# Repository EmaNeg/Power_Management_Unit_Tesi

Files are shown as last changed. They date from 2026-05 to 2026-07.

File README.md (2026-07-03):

# Power Management Unit (PMU) per Sistemi Embedded






<div align="center">
  <!-- Sostituisci con i nomi reali dei file immagine esportati -->
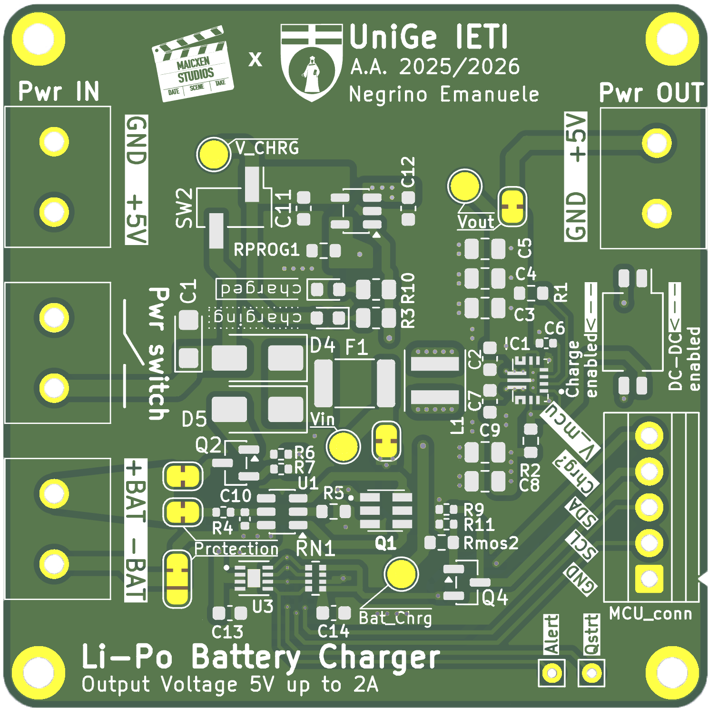
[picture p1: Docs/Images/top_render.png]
Render Top PCB
  
  &nbsp;&nbsp;&nbsp;&nbsp;&nbsp;&nbsp;&nbsp;&nbsp;&nbsp;&nbsp;&nbsp;&nbsp;&nbsp;&nbsp;&nbsp;&nbsp;&nbsp;&nbsp;
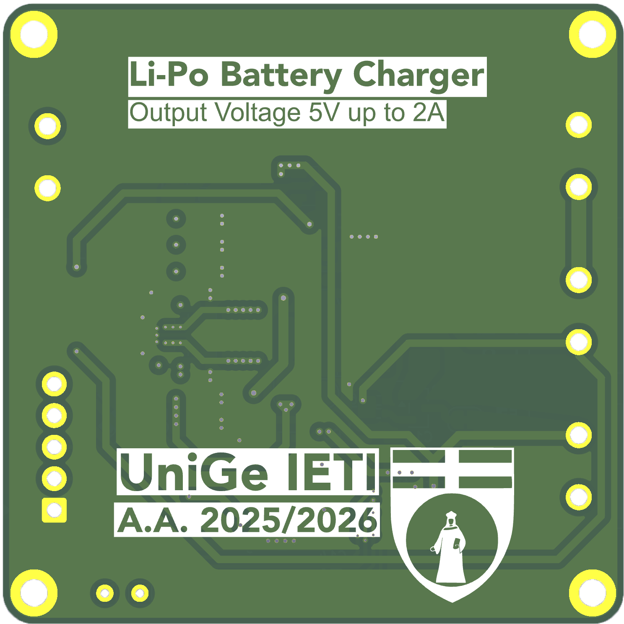
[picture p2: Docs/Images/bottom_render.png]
Render Bottom PCB
  
</div>

<br>

Questo repository contiene tutti i file di progettazione hardware, le simulazioni e le librerie software per una **Power Management Unit (PMU) integrata**, sviluppata come progetto di Tesi di Laurea Triennale in Ingegneria Elettronica e Tecnologie dell'Informazione presso l'Università degli Studi di Genova.

Il modulo (dimensioni 50x50 mm su PCB a due strati) è progettato per superare il divario tecnologico tra le tensioni variabili delle batterie ai Polimeri di Litio (Li-Po) e le specifiche di alimentazione stabili a 5V richieste dai carichi digitali, garantendo continuità di servizio e sicurezza operativa.

---

## ✨ Caratteristiche Principali (Features)

* **Power Path Management:** Commutazione automatica e trasparente tra sorgente esterna (5V) e batteria, dando priorità all'alimentazione di rete senza azzerare i transitori sul carico.
* **Conversione DC-DC:** Uscita stabile a 5V tramite convertitore Buck-Boost, operante in modo trasparente indipendentemente dallo stato di carica della cella (da 3.0V a 4.2V).
* **Ricarica Li-Po 1S:** Algoritmo CC-CV integrato basato su architettura lineare, con interruzione automatica a 4.2V.
* **Protezione Hardware (BMS):** Modulo di protezione contro sovrascarica (< 2.4V), sovraccarica (> 4.3V) e cortocircuiti.
* **Fuel Gauging I²C:** Stima accurata dello Stato di Carica (SOC) e *alert* hardware tramite algoritmo ModelGauge, senza necessità di resistenze di shunt, azzerando la deriva dell'errore.

---

## 🛠 Architettura Hardware

Il progetto è stato interamente sviluppato utilizzando **KiCad 9.0**. Il sistema si basa sui seguenti circuiti integrati:

| Sottosistema | Modello IC | Produttore | Funzione Principale |
| :--- | :--- | :--- | :--- |
| **DC-DC Converter** | TPS630701 | Texas Instruments | Convertitore Buck-Boost 2.4 MHz fisso a 5V. |
| **Battery Charger** | MCP73831 | Microchip | Controller lineare per ricarica Li-Po 1S (CC-CV). |
| **Fuel Gauge** | MAX17048 | Maxim Integrated | Sensore SOC I²C con algoritmo ModelGauge. |
| **Protection (BMS)** | DW01A + FS8205 | HM Semi / IC Fortune | IC di protezione batteria e doppio MOSFET N-Channel. |
| **Power Path** | DMP1045U-7 | Diodes Inc. | MOSFET P-Channel per commutazione automatica. |

---

## 📊 Prestazioni e Risultati Sperimentali

Il circuito è stato collaudato strumentalmente, registrando ottimi risultati in termini di efficienza energetica e stabilità del segnale:

* **Efficienza Energetica ($\eta$):** Compresa tra il **78.3%** (a pieno carico, ~1.25A) e il **90%** (a carico ridotto, ~100mA).
* **Ripple di Tensione:** Estremamente contenuto, registrando un picco massimo di **60 mV** a 300 mA (90 kHz) e **40 mV** a 1.4 A (390 kHz).
* **Carico Elettrico Massimale:** Il sistema sostiene in sicurezza carichi continui fino a **1.3A a 4.92V** (circa 6.4W in uscita) prima dell'intervento del fusibile resettabile hardware (tarato per sgancio a 1.6A).

<div align="center">
  <!-- Aggiungi nella repo l'immagine dei grafici dell'oscilloscopio se lo desideri -->
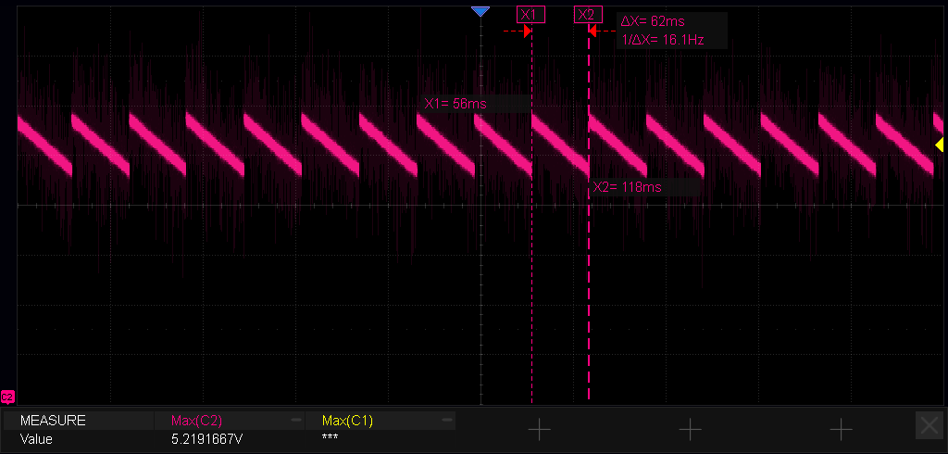
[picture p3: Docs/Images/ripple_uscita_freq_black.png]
Analisi Ripple Oscilloscopio
  
  &nbsp;&nbsp;&nbsp;&nbsp;&nbsp;&nbsp;
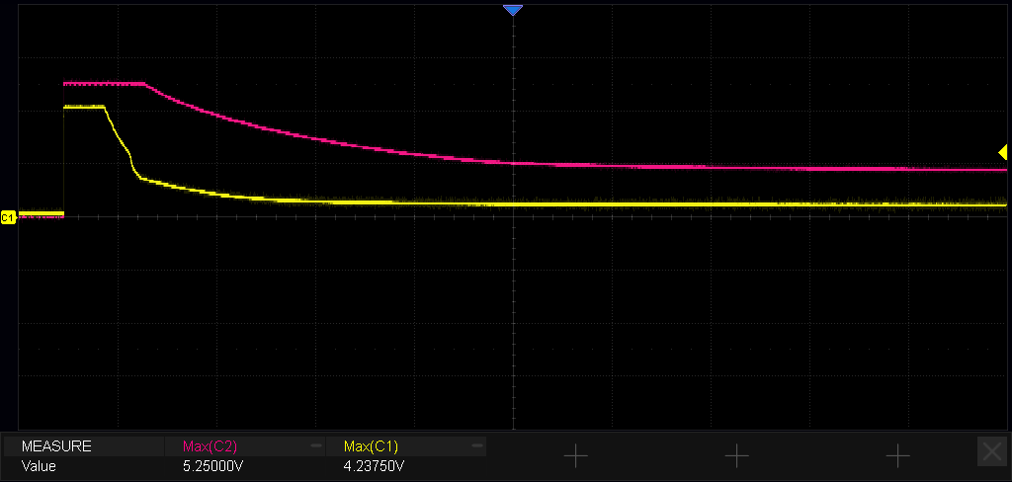
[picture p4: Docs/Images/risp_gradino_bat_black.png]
Risposta al Gradino
  
</div>

---

## 💻 Libreria Software (Firmware)

A supporto dell'hardware, è stata sviluppata una libreria firmware in **C++** dedicata al sensore MAX17048. 
La libreria permette ai microcontrollori host (es. Arduino, ESP32, STM32) di interfacciarsi facilmente con la PMU per:
- Lettura in tempo reale della tensione della cella ($V_{cell}$) e del SOC (%).
- Monitoraggio del rateo di ricarica/scarica tramite registro `CRATE`.
- Gestione interrupt hardware sul pin `ALRT` per avvisi di sotto-tensione programmabili e sleep mode per il risparmio energetico.

---

## 📁 Struttura della Repository

```text
├── Hardware/
│   ├── Kicad_files/        # File di progetto sorgente (Schematici, Layout PCB)
│   ├── Production/         # File Gerber e Drill pronti per la produzione industriale
│   ├── Assembly/           # File BOM (Bill of Materials) e CPL per assemblaggio SMT Pick & Place
│   └── 3D_Models/          # Rendering 3D della scheda top/bottom (STEP/PNG)
├── Simulations/            # File di simulazione SPICE dei blocchi funzionali (Proteus 8)
├── Firmware/               # Libreria C++ custom per MAX17048 e sketch di test (Arduino)
├── Datasheets/             # PDF dei datasheet originali dei componenti utilizzati
├── Docs/                   # Immagini, grafici di test termici/ripple, schemi e documentazione extra
└── README.md

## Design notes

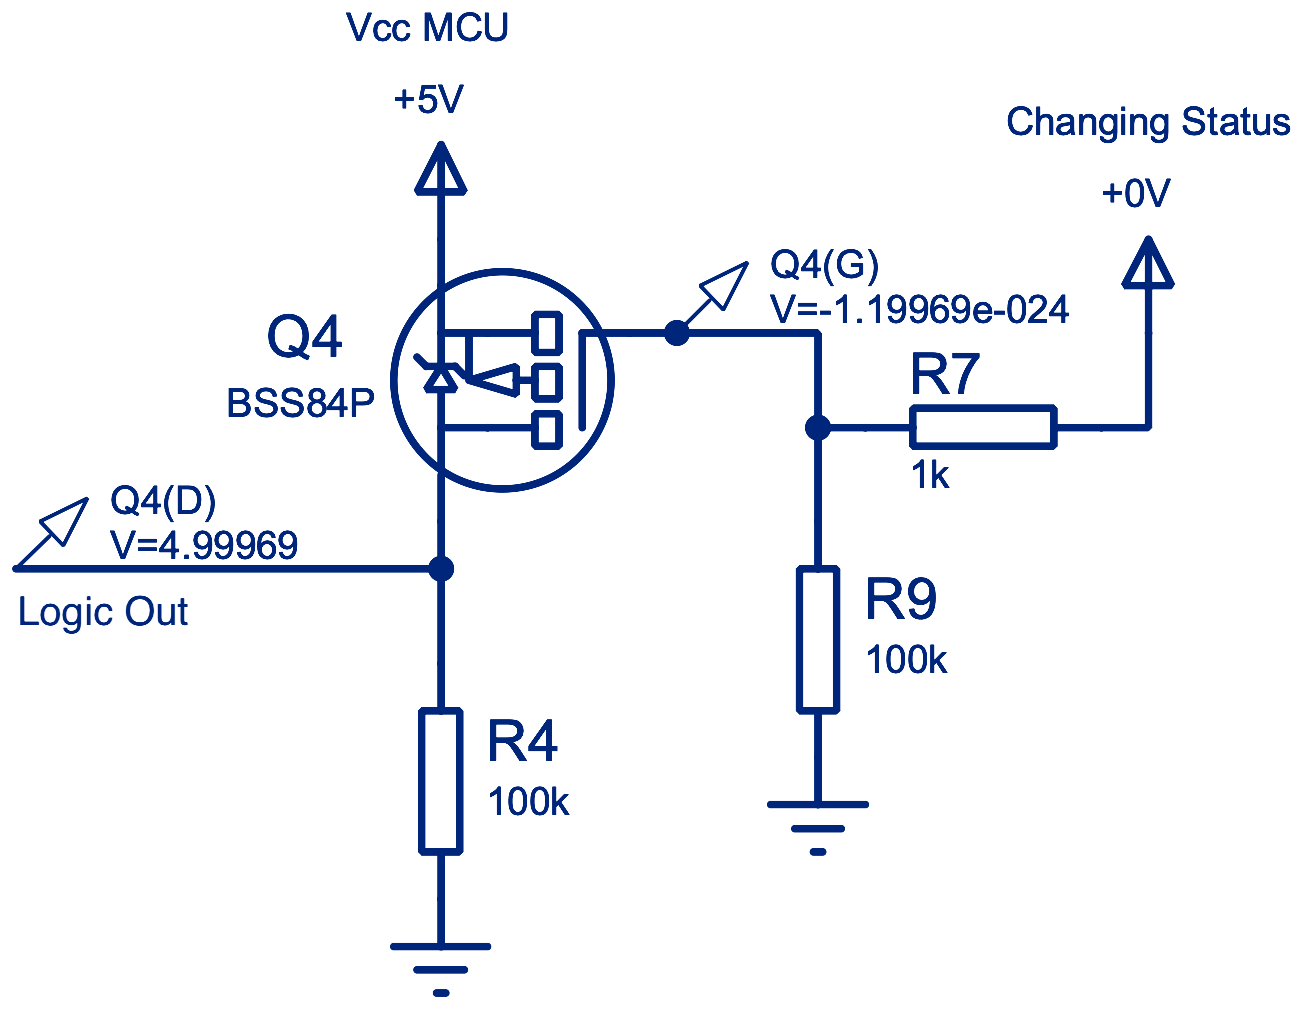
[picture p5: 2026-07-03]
Docs/Images/sim_en_charge_blue.png

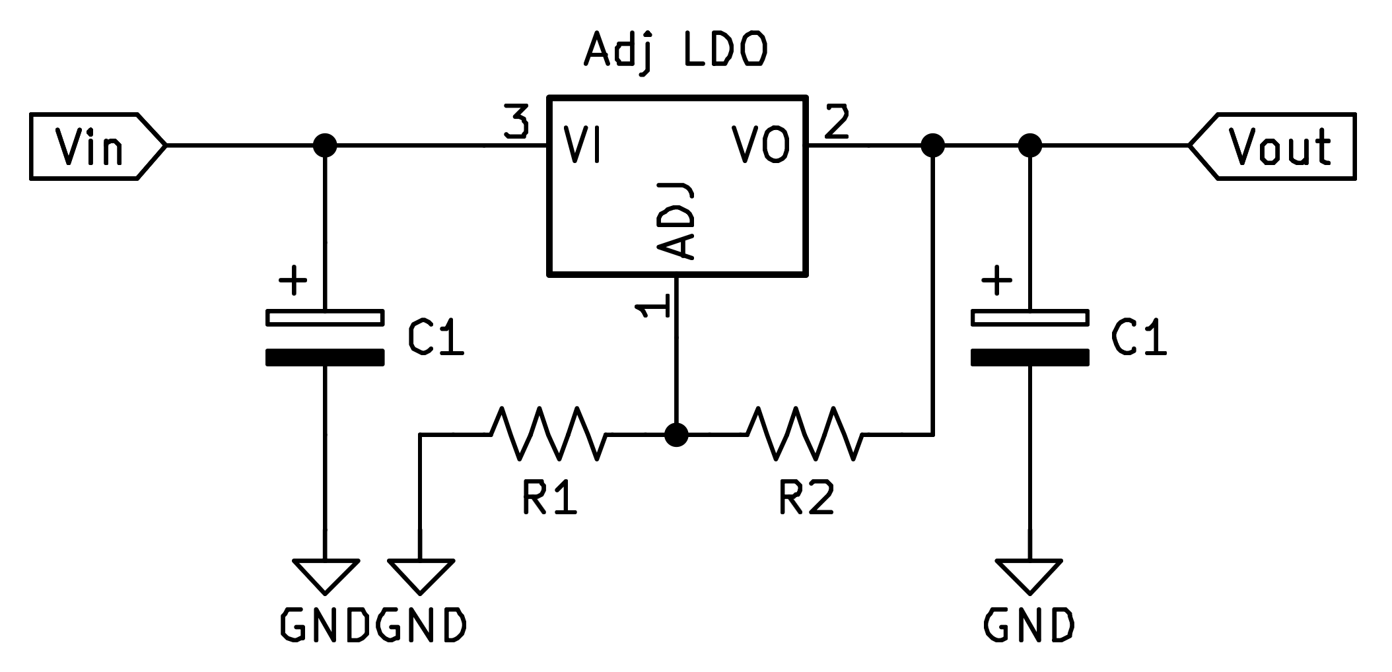
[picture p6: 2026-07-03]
Docs/Images/Adj_LDO.png

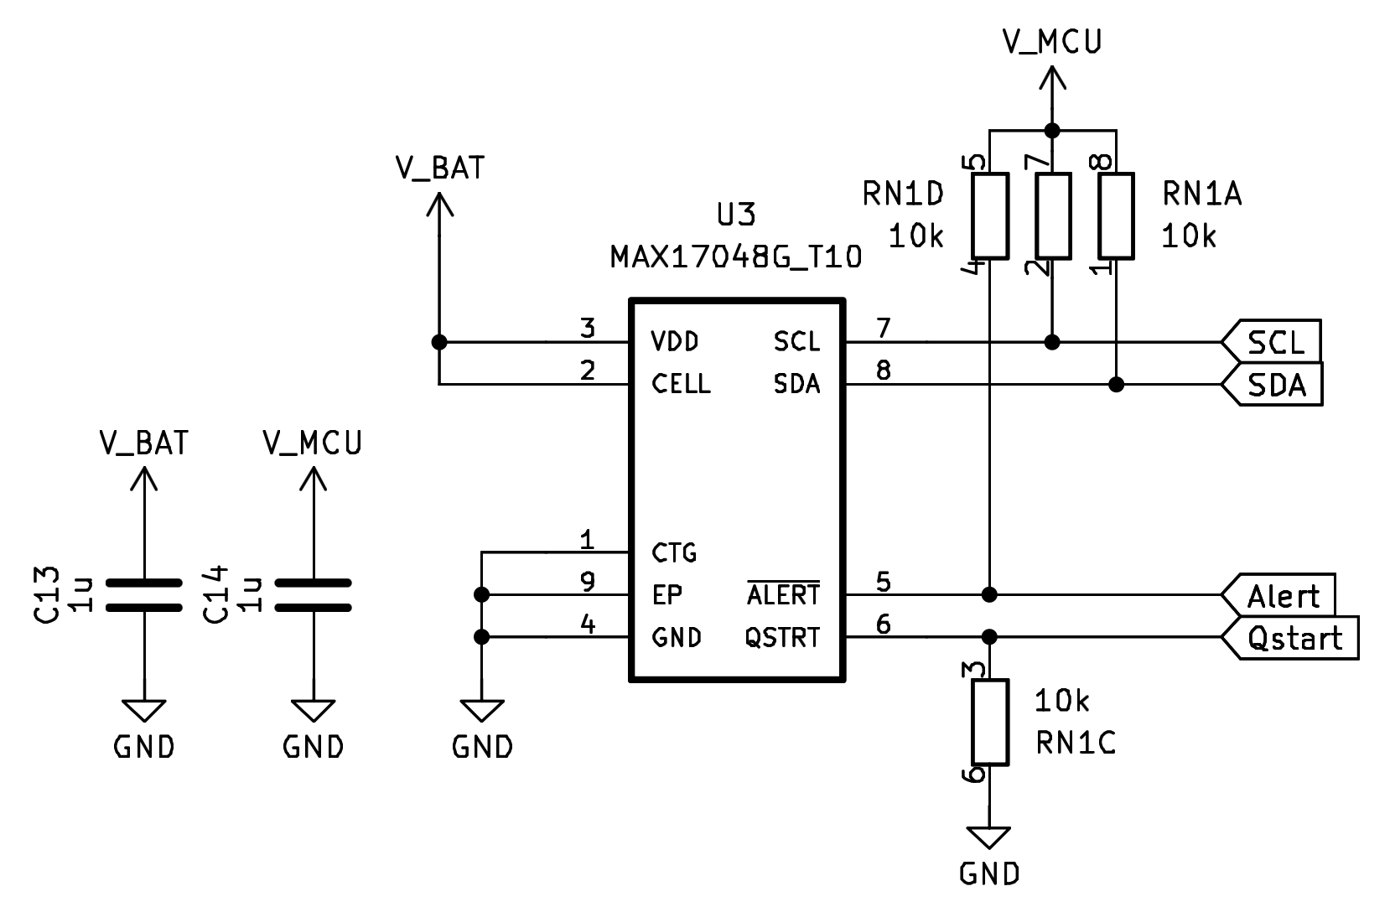
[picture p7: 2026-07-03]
Docs/Images/max17048.png

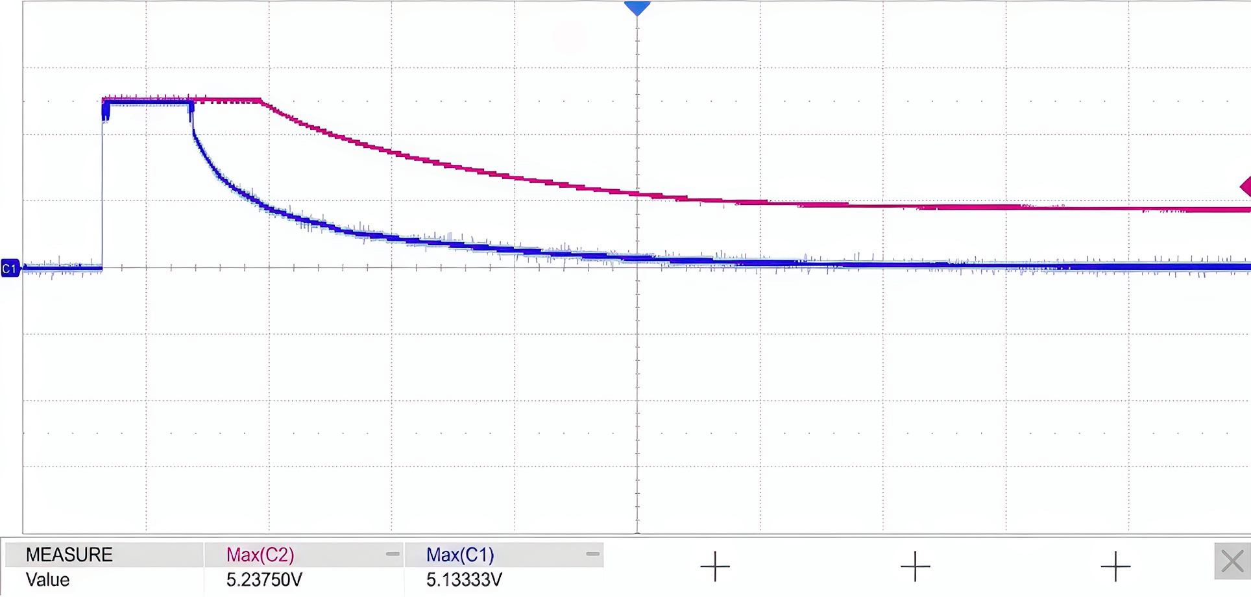
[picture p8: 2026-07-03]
Docs/Images/risp_gradino_ext.png

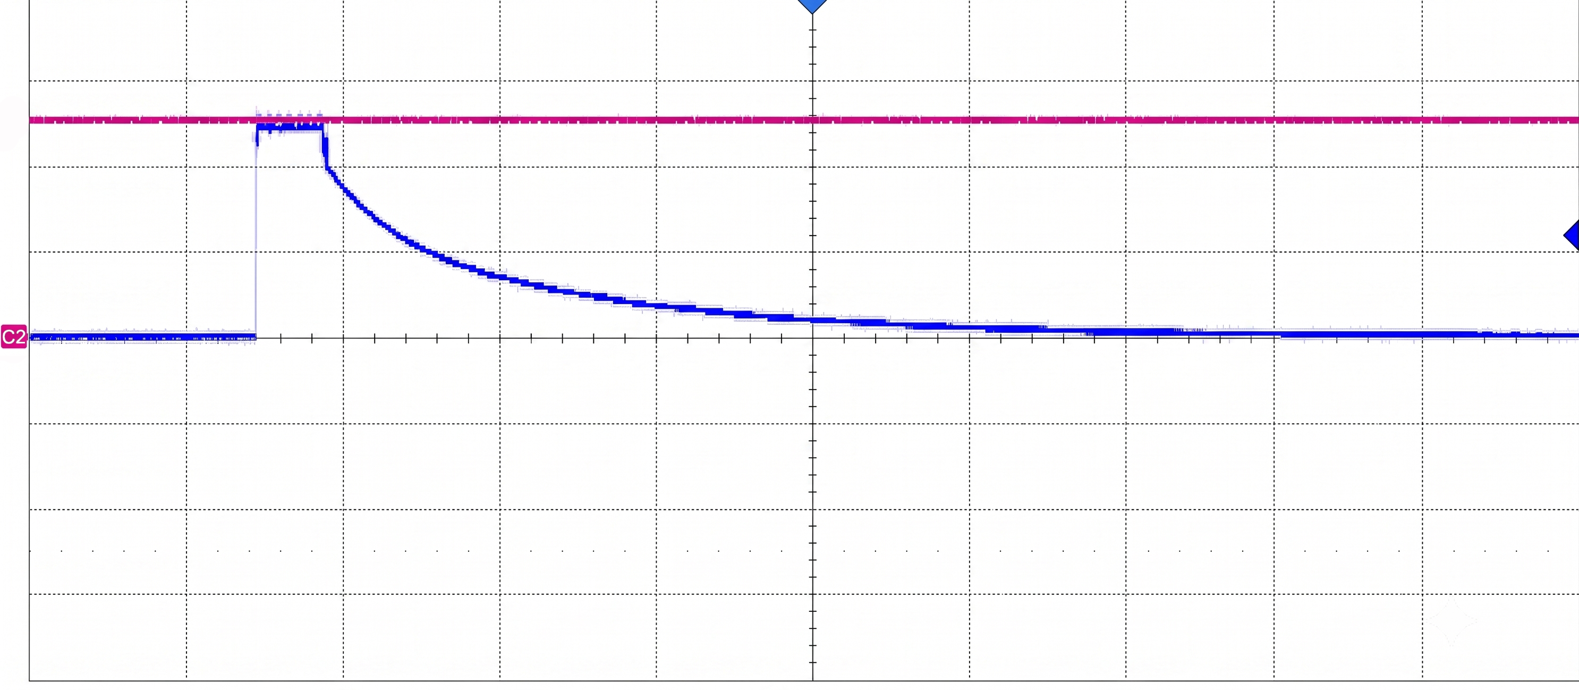
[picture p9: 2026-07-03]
Docs/Images/charge_pulse_crop.png

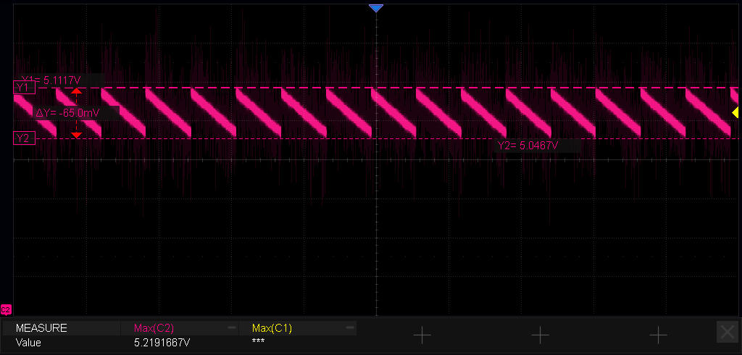
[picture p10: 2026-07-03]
Docs/Images/ripple_uscita_black.png

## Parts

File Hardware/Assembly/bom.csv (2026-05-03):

Designator | Footprint | Quantity | Value | LCSC Part #
C1 | CP_EIA-3216-18_Kemet-A | 1 | 10u
C10 | 0402 | 1 | 0.1u
C11, C12 | 0603 | 2 | 4.7u
C13, C14 | 0603 | 2 | 1u
C2, C7 | 0603 | 2 | 10u
C3, C4, C5 | 0805 | 3 | 22u
C6 | 0402 | 1 | 100n
C8, C9 | 0805 | 2 | 10u
D4, D5 | D_SMA | 2 | SS33
F1 | 1812 | 1 | 4A
IC1 | TPS630701RNMR | 1 | TPS63070RNMR
J1 | KF3012P | 1 | Ext_power_conn
J2 | KF3012P | 1 | Bat_conn
J3 | KF3012P | 1 | Out_conn
J4 | TerminalBlock_Xinya_XY308-2.54-5P_1x05_P2.54mm_Horizontal | 1 | MCU_conn
L1 | L_Coilcraft_XxL4020 | 1 | 1.5u
LED_A1 | 0603 | 1 | LED_amber
LED_G1 | 0603 | 1 | LED_green
Q1 | FS8205 | 1 | FS8205
Q2 | SOT-23-GATE | 1 | DMP1045U-7
Q4 | SOT-23 | 1 | BSS84
R1 | 0603 | 1 | 100k
R10, R3 | 0805 | 2 | 470R
R11, R6, R9 | 0402 | 3 | 100k
R2 | 0603 | 1 | 10k
R4, R7 | 0402 | 2 | 100R
R5, RMOS2 | 0603 | 2 | 1k
RN1 | R_Array_Convex_4x0402 | 1 | 10k
RPROG1 | 0603 | 1 | 2k
SW1 | KF3012P | 1 | Power_sw_conn
SW2 | PinHeader_1x02_P2.54mm_Vertical_SMD_Pin1Left | 1 | Switch_pins
SW3 | SW_DIP_SPSTx02_Slide_KingTek_DSHP02TS_W7.62mm_P1.27mm | 1 | SW_DIP_x02
TP1 | Pin_D0.7mm_L6.5mm_W1.8mm_FlatFork | 1 | Alert
TP2 | TestPoint_Pad_D2.0mm | 1 | Vout
TP3 | Pin_D0.7mm_L6.5mm_W1.8mm_FlatFork | 1 | Qstart
TP4 | TestPoint_Pad_D2.0mm | 1 | V_CHRG
TP6 | TestPoint_Pad_D2.0mm | 1 | Vin
TP7 | TestPoint_Pad_D2.0mm | 1 | Bat_Chrg
U1 | SOT-23-6 | 1 | DW01A
U2 | SOT-23-5 | 1 | MCP73831-2-OT
U3 | SON50P200X200X80-9N | 1 | MAX17048G_T10

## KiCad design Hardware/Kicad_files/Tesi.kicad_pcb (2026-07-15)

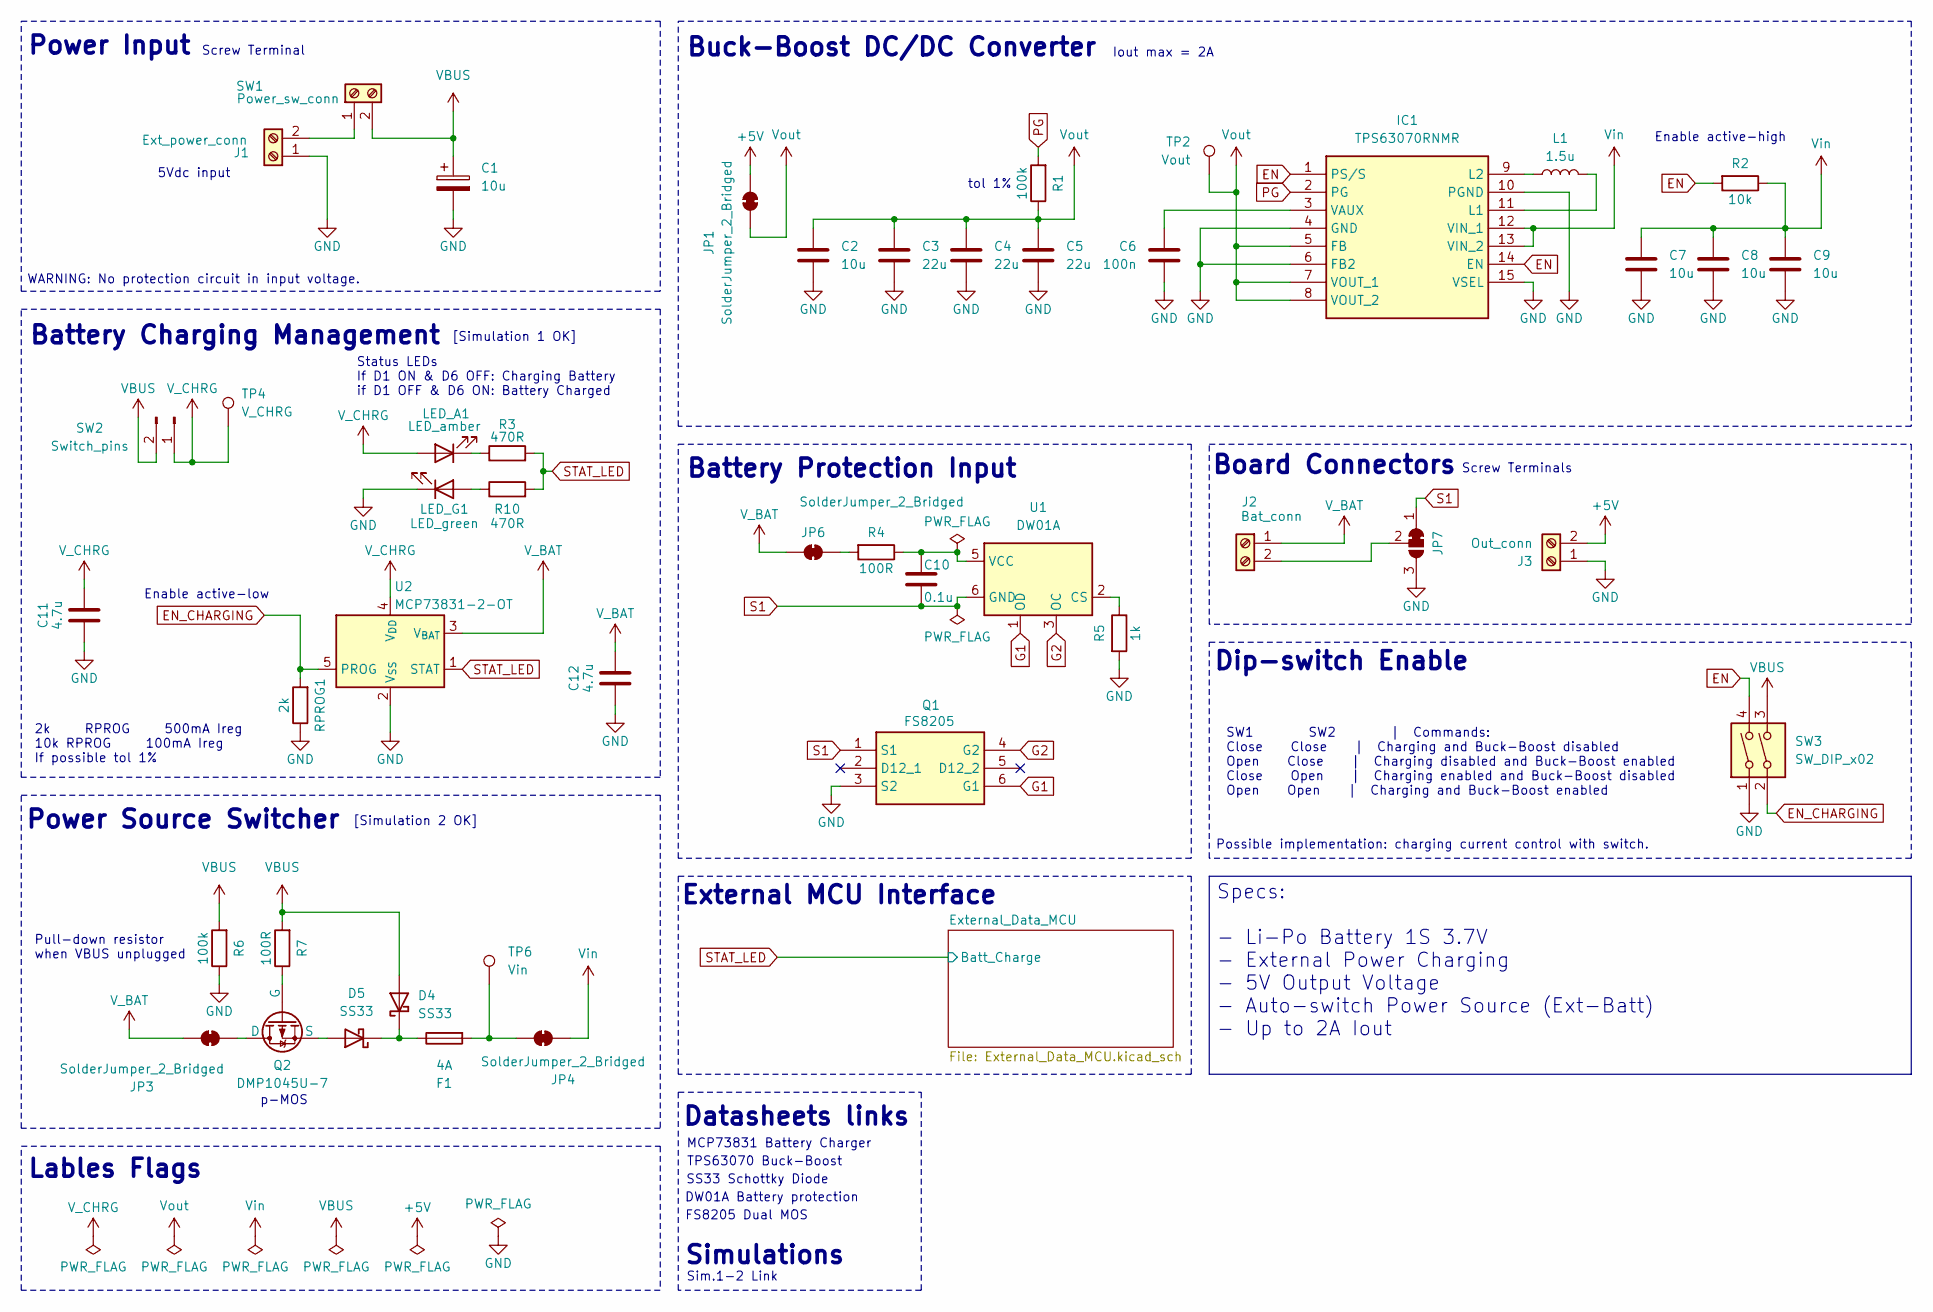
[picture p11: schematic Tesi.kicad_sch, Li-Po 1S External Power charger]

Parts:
C1: 10u; CP_EIA-3216-18_Kemet-A
C2, C7: 10u; C_0603_1608Metric
C3, C4, C5: 22u; C_0805_2012Metric
C6: 100n; C_0402_1005Metric
C8, C9: 10u; C_0805_2012Metric
C10: 0.1u; C_0402_1005Metric
C11, C12: 4.7u; C_0603_1608Metric
D4, D5: SS33; D_SMA
F1: 4A; Fuse_1812_4532Metric_Pad1.30x3.40mm_HandSolder
IC1: TPS63070RNMR; TPS630701RNMR; Manufacturer_Part_Number TPS63070RNMR; Mouser Part Number 595-TPS63070RNMR
J1: Ext_power_conn; KF3012P
J2: Bat_conn; KF3012P
J3: Out_conn; KF3012P
JP1, JP3, JP4, JP6: SolderJumper_2_Bridged; SolderJumper-2_P1.3mm_Bridged_RoundedPad1.0x1.5mm
JP7: SolderJumper_3_Bridged12; SolderJumper-3_P1.3mm_Bridged12_RoundedPad1.0x1.5mm_NumberL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
L1: 1.5u; L_Coilcraft_XxL4020
LED_A1: LED_amber; LED_0603_1608Metric
LED_G1: LED_green; LED_0603_1608Metric
Q1: FS8205; Manufacturer_Part_Number FS8205
Q2: DMP1045U-7; SOT-23-GATE
R1: 100k; R_0603_1608Metric
R2: 10k; R_0603_1608Metric
R3, R10: 470R; R_0805_2012Metric
R4, R7: 100R; R_0402_1005Metric
R5: 1k; R_0603_1608Metric
R6: 100k; R_0402_1005Metric
RPROG1: 2k; R_0603_1608Metric
SW1: Power_sw_conn; KF3012P
SW2: Switch_pins; PinHeader_1x02_P2.54mm_Vertical_SMD_Pin1Left
SW3: SW_DIP_x02; SW_DIP_SPSTx02_Slide_KingTek_DSHP02TS_W7.62mm_P1.27mm
TP2: Vout; TestPoint_Pad_D2.0mm
TP4: V_CHRG; TestPoint_Pad_D2.0mm
TP6: Vin; TestPoint_Pad_D2.0mm
U1: DW01A; SOT-23-6
U2: MCP73831-2-OT; SOT-23-5

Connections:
+5V: J3.2, JP1.2 (B)
EN: IC1.1 (PS/S), IC1.14 (EN), R2.2, SW3.4
EN_CHARGING: RPROG1.2, SW3.2, U2.5 (PROG)
G1: Q1.6 (G1), U1.1 (OD)
G2: Q1.4 (G2), U1.3 (OC)
GND: C1.2, C2.2, C3.2, C4.2, C5.2, C6.2, C7.2, C8.2, C9.2, C11.1, C12.1, IC1.4 (GND), IC1.6 (FB2), IC1.10 (PGND), IC1.15 (VSEL), J1.1, J3.1, JP7.3 (B), LED_G1.1 (K), Q1.3 (S2), R5.2, R6.1, RPROG1.1, SW3.1, U2.2 (V_{SS}); also elsewhere on the board
unnamed: D4.1 (K), D5.1 (K), F1.1
unnamed: D5.2 (A), Q2.3 (S)
unnamed: IC1.11 (L1), L1.2
unnamed: IC1.9 (L2), L1.1
unnamed: C6.1, IC1.3 (VAUX)
unnamed: J1.2, SW1.1
unnamed: J2.2, JP7.2 (C)
unnamed: JP3.2 (B), Q2.1 (D)
unnamed: F1.2, JP4.1 (A), TP6.1
unnamed: JP6.2 (B), R4.2
unnamed: LED_A1.1 (K), R3.1
unnamed: LED_G1.2 (A), R10.1
unnamed: Q2.2 (G), R7.1
unnamed: R5.1, U1.2 (CS)
unnamed: C10.2, R4.1, U1.5 (VCC)
PG: IC1.2 (PG), R1.2
S1: C10.1, JP7.1 (A), Q1.1 (S1), U1.6 (GND)
STAT_LED: R3.2, R10.2, U2.1 (STAT); also elsewhere on the board
VBUS: C1.1, D4.2 (A), R6.2, R7.2, SW1.2, SW2.2, SW3.3
V_BAT: C12.2, J2.1, JP3.1 (A), JP6.1 (A), U2.3 (V_{BAT}); also elsewhere on the board
V_CHRG: C11.2, LED_A1.2 (A), SW2.1, TP4.1, U2.4 (V_{DD})
Vin: C7.1, C8.1, C9.1, IC1.12 (VIN_1), IC1.13 (VIN_2), JP4.2 (B), R2.1
Vout: C2.1, C3.1, C4.1, C5.1, IC1.5 (FB), IC1.7 (VOUT_1), IC1.8 (VOUT_2), JP1.1 (A), R1.1, TP2.1

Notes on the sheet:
tol 1%
Power Input
Buck-Boost DC/DC Converter
Lables Flags
Power Source Switcher
Enable active-low
2k RPROG 500mA Ireg 10k RPROG 100mA Ireg If possible tol 1%
Iout max = 2A
Battery Protection Input
[Simulation 2 OK]
Simulations
Enable active-high
MCP73831 Battery Charger
p-MOS
Screw Terminals
External MCU Interface
TPS63070 Buck-Boost
Battery Charging Management
5Vdc input
Datasheets links
FS8205 Dual MOS
[Simulation 1 OK]
DW01A Battery protection
Possible implementation: charging current control with switch.
Board Connectors
SW1 SW2 | Commands: Close Close | Charging and Buck-Boost disabled Open Close | Charging disabled and Buck-Boost enabled Close Open | Charging enabled and Buck-Boost disabled Open Open | Charging and Buck-Boost enabled
SS33 Schottky Diode
WARNING: No protection circuit in input voltage.
Status LEDs If D1 ON & D6 OFF: Charging Battery if D1 OFF & D6 ON: Battery Charged
Dip-switch Enable
Screw Terminal
Pull-down resistor when VBUS unplugged
Sim.1-2 Link
Specs: - Li-Po Battery 1S 3.7V - External Power Charging - 5V Output Voltage - Auto-switch Power Source (Ext-Batt) - Up to 2A Iout

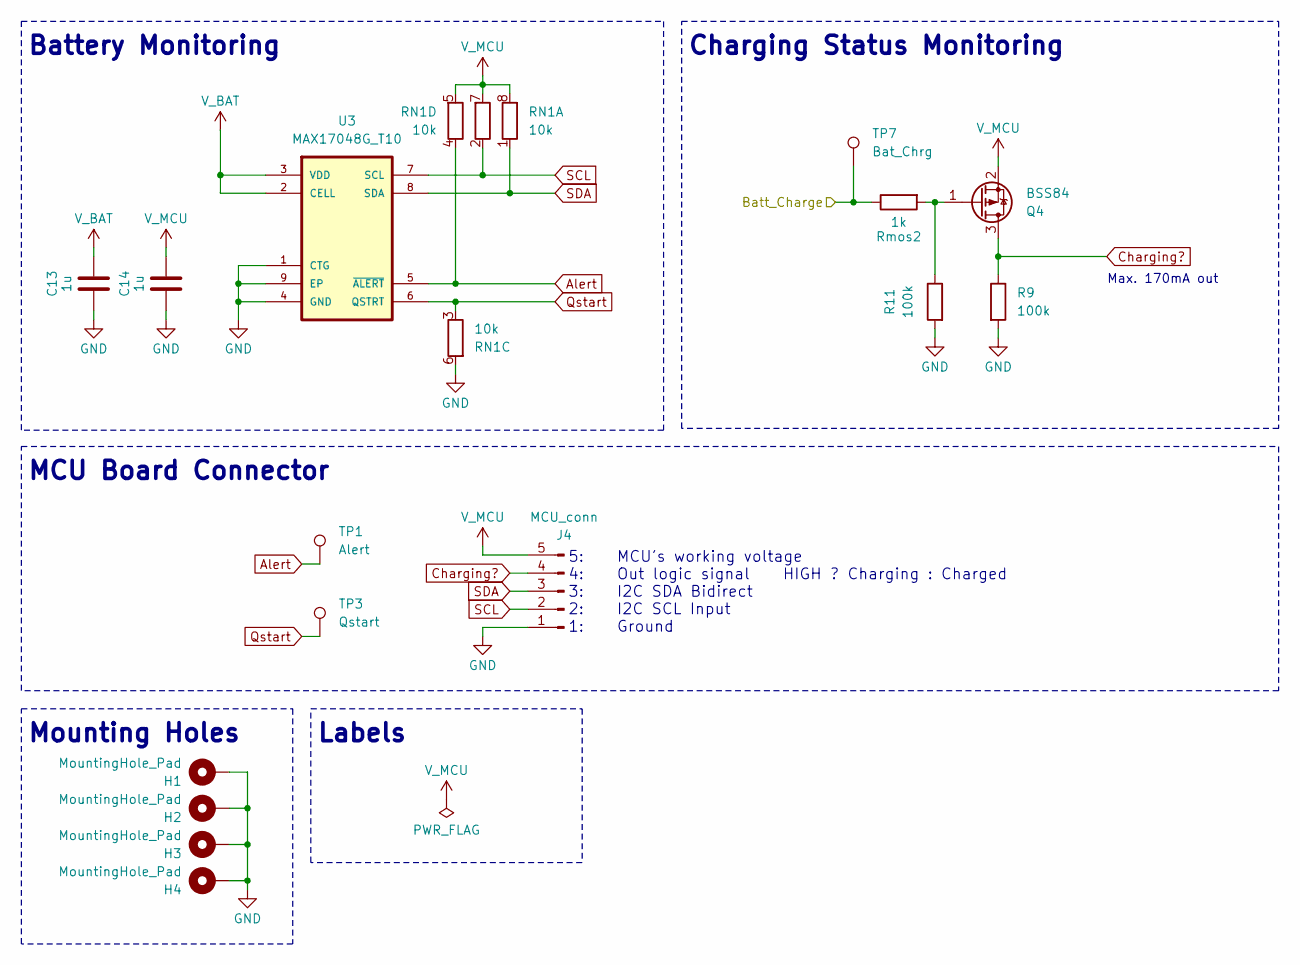
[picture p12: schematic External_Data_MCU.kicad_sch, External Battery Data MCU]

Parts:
C13, C14: 1u; C_0603_1608Metric
H1, H2, H3, H4: MountingHole_Pad; MountingHole_2.2mm_M2_DIN965_Pad
J4: MCU_conn; TerminalBlock_Xinya_XY308-2.54-5P_1x05_P2.54mm_Horizontal
Q4: BSS84; SOT-23
R9, R11: 100k; R_0402_1005Metric
RN1: 10k; R_Array_Convex_4x0402
Rmos2: 1k; R_0603_1608Metric
TP1: Alert; Pin_D0.7mm_L6.5mm_W1.8mm_FlatFork
TP3: Qstart; Pin_D0.7mm_L6.5mm_W1.8mm_FlatFork
TP7: Bat_Chrg; TestPoint_Pad_D2.0mm
U3: MAX17048G_T10; SON50P200X200X80-9N

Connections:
Alert: RN1.4 (R4.1), TP1.1, U3.5 (~ALERT)
Charging?: J4.4, Q4.3 (D), R9.1
GND: C13.1, C14.1, H1.1, H2.1, H3.1, H4.1, J4.1, R9.2, R11.2, RN1.6 (R3.2), U3.1 (CTG), U3.4 (GND), U3.9 (EP); also elsewhere on the board
unnamed: Q4.1 (G), R11.1, Rmos2.2
Qstart: RN1.3 (R3.1), TP3.1, U3.6 (QSTRT)
SCL: J4.2, RN1.2 (R2.1), U3.7 (SCL)
SDA: J4.3, RN1.1 (R1.1), U3.8 (SDA)
STAT_LED: Rmos2.1, TP7.1; also elsewhere on the board
V_BAT: C13.2, U3.2 (CELL), U3.3 (VDD); also elsewhere on the board
V_MCU: C14.2, J4.5, Q4.2 (S), RN1.5 (R4.2), RN1.7 (R2.2), RN1.8 (R1.2)

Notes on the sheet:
Max. 170mA out
Mounting Holes
MCU Board Connector
Labels
Battery Monitoring
Charging Status Monitoring
5: MCU's working voltage 4: Out logic signal HIGH ? Charging : Charged 3: I2C SDA Bidirect 2: I2C SCL Input 1: Ground

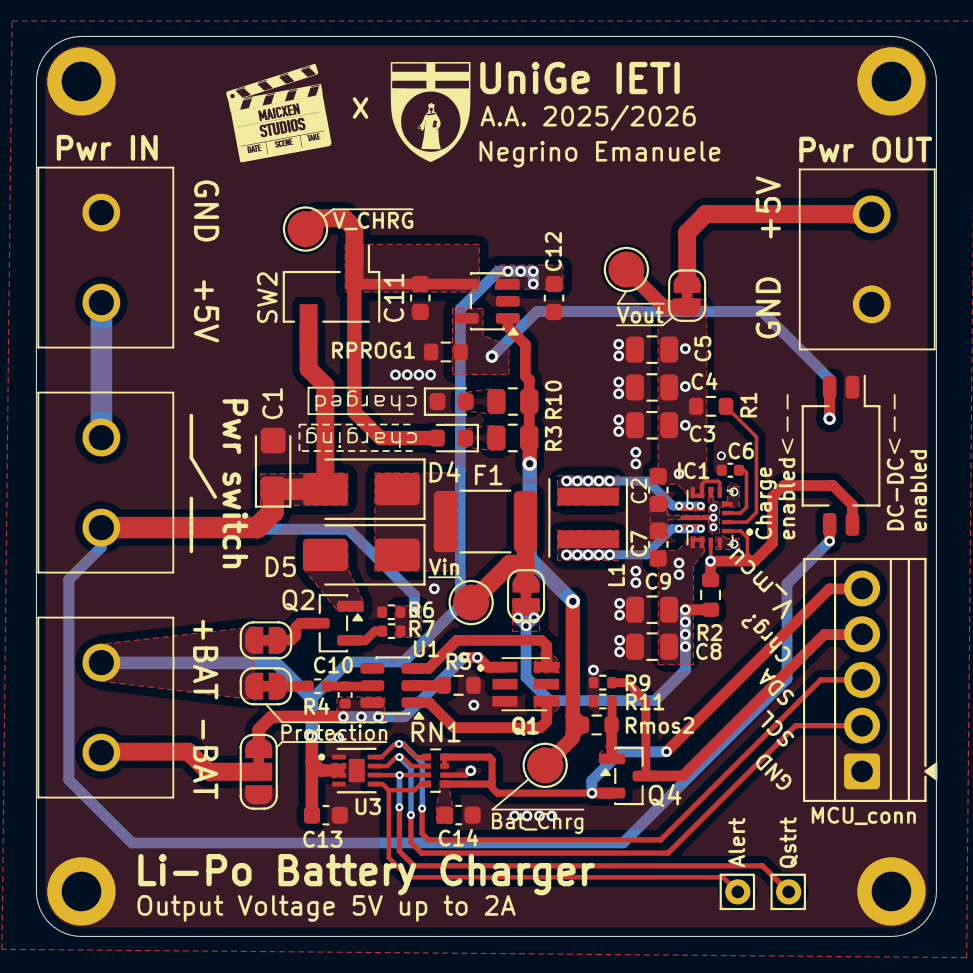
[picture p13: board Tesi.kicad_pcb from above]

Board: 2 copper layers, 50.0 x 50.0 mm, 62 parts (0 on the bottom side), 36 nets.

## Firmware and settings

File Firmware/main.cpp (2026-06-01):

/**
 * @file main.cpp
 * @brief Script principale di test e validazione per la libreria MAX17048_Gauge.
 * * Questo firmware inizializza il sensore sul bus I2C, imposta le soglie critiche 
 * per gli allarmi hardware e legge periodicamente i dati telemetrici della batteria
 * (Tensione, SOC, Tasso di Carica), stampandoli sul monitor seriale.
 * * @author Emanuele Negrino
 * @date 2026
 */

#include <Arduino.h>
#include <Wire.h>
#include "MAX17048_Gauge.h"

MAX17048_Gauge battery; ///< Istanza globale del Fuel Gauge

float estimateCurrent_mA(float batteryCapacity_mAh);

/**
 * @brief Routine di inizializzazione.
 * Esegue il setup della porta seriale, del bus I2C, verifica la presenza 
 * dell'hardware e configura i parametri operativi del MAX17048.
 */
void setup() {
  Serial.begin(115200);
  while (!Serial) delay(10); // Attesa per schede native USB come Arduino R4 o ESP32
  
  Serial.println(F("\n--- MAX17048 Test ---"));

  // 1. Inizializzazione Hardware
  if (!battery.begin(Wire)) {
    Serial.println(F("ERRORE: Sensore non trovato!"));
  }

  // 2. Informazioni sul Chip
  Serial.print(F("Versione IC: 0x"));
  Serial.println(battery.getICversion(), HEX); // Lettura attesa: 0x0011 o 0x0010
  Serial.print(F("Chip ID: 0x"));
  Serial.println(battery.getChipID(), HEX);

  // 3. Configurazione Soglie Alert
  battery.setAlertVoltages(3.2, 4.25); // Limiti di Tensione: Min 3.2V, Max 4.25V
  battery.setLowSOCThreshold(15);      // Limite di Capacità: Alert sotto il 15%
  
  // 4. Pulizia Iniziale
  // Fondamentale per rimuovere il flag 'Reset Indicator' (RI) che scatta fisicamente 
  // ogni volta che il chip riceve alimentazione iniziale.
  battery.clearAllAlerts();
  
  Serial.println(F("Setup completato con successo.\n"));
}

/**
 * @brief Routine di loop principale.
 * Campiona i dati dal chip I2C e gestisce dinamicamente gli interrupt hardware 
 * (tramite polling in questo caso) qualora i valori superino le soglie definite.
 */
void loop() {
  // Lettura dati telemetrici principali
  float voltage = battery.getVoltage();
  float soc     = battery.getSOC();
  float rate    = battery.getChangeRate();
  bool charging = battery.isCharging();

  // Output Dati in formato Tabellare per analisi seriale
  Serial.print(F("V: "));     Serial.print(voltage, 3); Serial.print(F("V | "));
  Serial.print(F("SOC: "));   Serial.print(soc, 1);     Serial.print(F("% | "));
  Serial.print(F("Rate: "));  Serial.print(rate, 2);    Serial.print(F("%/h | "));
  Serial.print(F("Stato: ")); Serial.println(charging ? F("IN CARICA") : F("A BATTERIA"));

  // Gestione e decodifica degli Alert Hardware registrati dal chip
  if (battery.isActiveAlert()) {
    uint8_t status = battery.getAlertStatus();
    Serial.print(F(">>> ALERT ATTIVO (0x")); Serial.print(status, HEX); Serial.println(F(") <<<"));

    // Analisi Bit a Bit del registro di Status
    if (status & MAX1704X_ALERTFLAG_VOLTAGE_HIGH) Serial.println(F("    - Sovratensione (>4.25V)"));
    if (status & MAX1704X_ALERTFLAG_VOLTAGE_LOW)  Serial.println(F("    - Sottotensione (<3.2V)"));
    if (status & MAX1704X_ALERTFLAG_SOC_LOW)      Serial.println(F("    - Batteria Scarica (<15%)"));
    if (status & MAX1704X_ALERTFLAG_SOC_CHANGE)   Serial.println(F("    - Variazione SOC 1%"));
    
    // Auto-Reset Logico: pulisce l'allarme solo se i parametri sono tornati in sicurezza
    if (voltage > 3.25 && voltage < 4.20 && soc > 16) {
      Serial.println(F("    - Parametri rientrati: Resetto Alert Hardware."));
      battery.clearAllAlerts();
    }
  }

  Serial.println(F("---------------------------------------------------------"));
  delay(2000);
}

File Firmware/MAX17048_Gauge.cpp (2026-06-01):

/**
 * @file MAX17048_Gauge.cpp
 * @brief Implementazione della libreria MAX17048_Gauge.
 * * Contiene l'implementazione dei metodi per la comunicazione I2C, la gestione 
 * degli stati e la decodifica dei registri hardware del MAX17048.
 */

#include "MAX17048_Gauge.h"

MAX17048_Gauge::MAX17048_Gauge() {}

MAX17048_Gauge::~MAX17048_Gauge() {}

// ==============================================================================
// I2C CORE OTTIMIZZATO (CON AUTO-RETRY)
// ==============================================================================

uint16_t MAX17048_Gauge::readRegister(uint8_t reg) {
    // Tenta la lettura fino a 3 volte per filtrare eventuali disturbi elettrici (EMI)
    for (uint8_t retries = 0; retries < 3; retries++) {
        _i2cPort->beginTransmission(_address);
        _i2cPort->write(reg);
        
        // Chiudiamo la trasmissione in modo netto per pulire il bus
        if (_i2cPort->endTransmission() == 0) { 
            if (_i2cPort->requestFrom(_address, (uint8_t)2) == 2) {
                uint16_t value = _i2cPort->read() << 8;
                value |= _i2cPort->read();
                return value; // Lettura andata a buon fine
            }
        }
        delay(5); // Pausa prima di riprovare
    }
    
    // In caso di guasto totale del bus, restituisce 0x0000.
    // Questo evita i NAN matematici, i finti allarmi 0x7F e i falsi Rate negativi.
    return 0x0000; 
}

bool MAX17048_Gauge::writeRegister(uint8_t reg, uint16_t value) {
    // Tenta la scrittura fino a 3 volte
    for (uint8_t retries = 0; retries < 3; retries++) {
        _i2cPort->beginTransmission(_address);
        _i2cPort->write(reg);
        _i2cPort->write(value >> 8);   // Invia MSB (Big-Endian)
        _i2cPort->write(value & 0xFF); // Invia LSB
        
        uint8_t error = _i2cPort->endTransmission();
        
        if (error == 0) return true;
        
        // Se inviamo il comando di Soft Reset, l'IC si riavvia istantaneamente
        // causando un NACK hardware intenzionale. Ignoriamo questo specifico errore.
        if (reg == MAX1704X_CMD_REG) return true; 
        
        delay(5);
    }
    return false;
}

// ==============================================================================
// INIT E CONTROLLO HARDWARE
// ==============================================================================

bool MAX17048_Gauge::begin(TwoWire &wirePort) {
    _i2cPort = &wirePort;
    _i2cPort->begin();

    if (!isDeviceReady()) return false; 
    if (!reset()) return false;

    enableSleep(false);
    sleep(false);
    
    return true;
}

uint16_t MAX17048_Gauge::getICversion() {
    return readRegister(MAX1704X_VERSION_REG);
}

uint8_t MAX17048_Gauge::getChipID() {
    return readRegister(MAX1704X_VRESET_REG) & 0xFF;
}

bool MAX17048_Gauge::isDeviceReady() {
    return (getICversion() & 0xFFF0) == 0x0010;
}

bool MAX17048_Gauge::reset() {
    writeRegister(MAX1704X_CMD_REG, 0x5400);
    delay(10); 

    // Pulisce l'alert di "Reset Indicator" generato dall'accensione
    for (uint8_t retries = 0; retries < 3; retries++) {
        if (clearAlertFlag(MAX1704X_ALERTFLAG_RESET_INDICATOR)) {
            return true;
        }
        delay(10);
    }
    return false;
}

void MAX17048_Gauge::quickStart() {
    uint16_t mode = readRegister(MAX1704X_MODE_REG);
    mode |= (1 << 14); 
    writeRegister(MAX1704X_MODE_REG, mode);
}

// ==============================================================================
// LETTURE PRINCIPALI
// ==============================================================================

float MAX17048_Gauge::getVoltage() {
    return readRegister(MAX1704X_VCELL_REG) * 0.000078125f; 
}

float MAX17048_Gauge::getSOC() {
    return readRegister(MAX1704X_SOC_REG) / 256.0f;
}

float MAX17048_Gauge::getChangeRate() {
    // Il cast a int16_t permette di gestire correttamente i valori negativi (scarica)
    return (int16_t)readRegister(MAX1704X_CRATE_REG) * 0.208f; 
}

bool MAX17048_Gauge::isCharging() {
    float rate = getChangeRate();

    // Macchina a stati con isteresi per filtrare il rumore analogico
    if (_isChargingState) {
        if (rate < 0.1f) _isChargingState = false; 
    } else {
        if (rate > 0.5f) _isChargingState = true;  
    }
    return _isChargingState;
}

// ==============================================================================
// GESTIONE ALERT
// ==============================================================================

void MAX17048_Gauge::setLowSOCThreshold(uint8_t percent) {
    percent = constrain(percent, 1, 32);
    uint16_t config = readRegister(MAX1704X_CONFIG_REG);
    config &= 0xFFE0; // Pulisce i 5 bit bassi
    config |= (32 - percent);
    writeRegister(MAX1704X_CONFIG_REG, config);
}

void MAX17048_Gauge::setAlertVoltages(float minv, float maxv) {
    uint8_t minVal = constrain((int)(minv / 0.020f), 0, 255);
    uint8_t maxVal = constrain((int)(maxv / 0.020f), 0, 255);
    // MSB = Soglia Minima, LSB = Soglia Massima
    writeRegister(MAX1704X_VALERT_REG, (minVal << 8) | maxVal);
}

void MAX17048_Gauge::getAlertVoltages(float &minv, float &maxv) {
    uint16_t valrt = readRegister(MAX1704X_VALERT_REG);
    minv = (valrt >> 8) * 0.020f;
    maxv = (valrt & 0xFF) * 0.020f;
}

bool MAX17048_Gauge::isActiveAlert() {
    return (readRegister(MAX1704X_CONFIG_REG) & (1 << 5)) > 0;
}

uint8_t MAX17048_Gauge::getAlertStatus() {
    return (readRegister(MAX1704X_STATUS_REG) >> 8) & 0x7F;
}

bool MAX17048_Gauge::clearAlertFlag(uint8_t flag) {
    uint16_t status = readRegister(MAX1704X_STATUS_REG);
    status &= ~((uint16_t)flag << 8); 
    writeRegister(MAX1704X_STATUS_REG, status);
    return (getAlertStatus() & flag) == 0;
}

void MAX17048_Gauge::clearAllAlerts() {
    uint16_t status = readRegister(MAX1704X_STATUS_REG);
    status &= 0x00FF; // Pulisce i flag nel MSB
    writeRegister(MAX1704X_STATUS_REG, status);
    
    uint16_t config = readRegister(MAX1704X_CONFIG_REG);
    config &= ~(1 << 5); // Disasserisce il pin fisico ALRT
    writeRegister(MAX1704X_CONFIG_REG, config);
}

// ==============================================================================
// GESTIONE VRESET
// ==============================================================================

void MAX17048_Gauge::setResetVoltage(float reset_v) {
    uint16_t reg = readRegister(MAX1704X_VRESET_REG);
    uint8_t val = constrain((int)(reset_v / 0.040f), 0, 127); 
    reg = (reg & 0x00FF) | (val << 8); 
    writeRegister(MAX1704X_VRESET_REG, reg);
}

float MAX17048_Gauge::getResetVoltage() {
    return (readRegister(MAX1704X_VRESET_REG) >> 8) * 0.040f;
}

// ==============================================================================
// POWER MANAGEMENT E HIBERNATION
// ==============================================================================
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

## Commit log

2026-05-03 Added kicad files
    [External_Data_MCU.kicad_sch, Tesi.kicad_pcb, Tesi.kicad_sch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]
2026-07-15 Added library footprint
    [Tesi.kicad_pcb]

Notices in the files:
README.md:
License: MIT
